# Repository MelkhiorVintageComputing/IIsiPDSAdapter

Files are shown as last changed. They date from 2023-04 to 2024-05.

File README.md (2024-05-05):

# PDS Adapter for the Macintosh IIsi

This repository contains recreated PDS adapters for the Macintosh IIsi.

They include a small switch to select the FPU clock, either the CPU clock (20 MHz) or the on-board oscillator (whatever 5V, DIP-8 or DIP-14 oscillator is soldered).

## PLCC

MC68882 FPU tested and working at 20 MHz (system clock)

MC68882 FPU tested and working at 25 MHz (on-board oscillator).

MC68882 FPU tested at 32 MHz, but if the adapter is stand-alone Error 11 occurs when using the FPU. When a [IIsiFPGA](https://github.com/rdolbeau/IIsiFPGA) is plugged in the second slot, 32 MHz seems to work reliably. Current hypothesis is some signal integrity issue when no PDS board is plugged in the adapter.

## PGA

MC68882 FPU tested and working at 20 MHz (system clock)

MC68882 FPU tested and working at 40 MHz (on-board oscillator), using a genuine XC68882RC40

Also known to work at 40 MHz with a IIsiFPGA in the second slot.

## PGA-DUAL

MC68882 FPU tested and working at 20 MHz (system clock) alongside a IIsiFPGA ans IIsiSEthernet, although [with some questions about signal integrity and/or timings](https://68kmla.org/bb/index.php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).

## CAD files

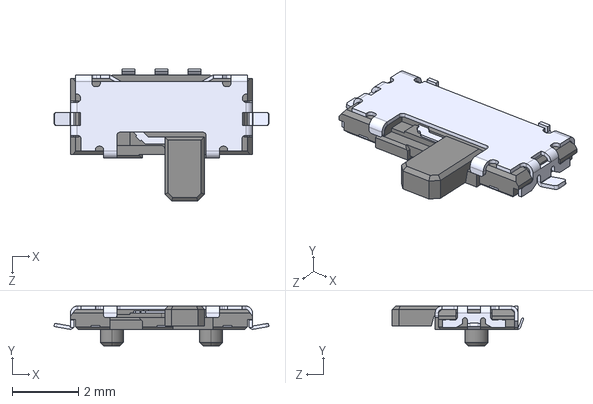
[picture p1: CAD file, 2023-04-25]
PGA_DUAL/SSAJ110100.step
6.50 x 1.20 x 3.98 mm

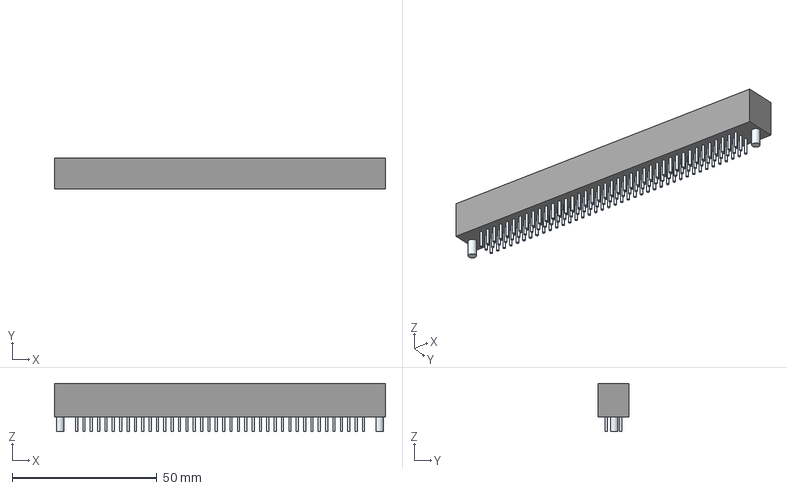
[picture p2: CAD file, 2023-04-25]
PGA_DUAL/5535098-5.stp
114.3 x 10.6 x 16.6 mm
Leads

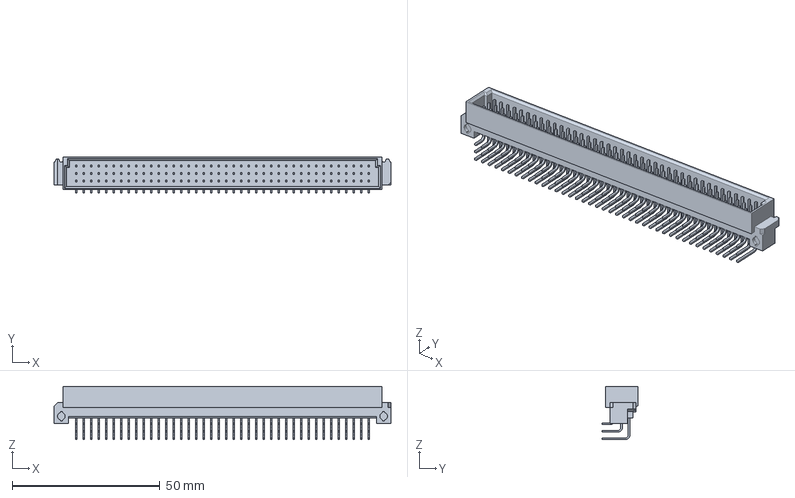
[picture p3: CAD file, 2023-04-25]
PGA_DUAL/650906-5.stp
114.2 x 12.1 x 18.0 mm

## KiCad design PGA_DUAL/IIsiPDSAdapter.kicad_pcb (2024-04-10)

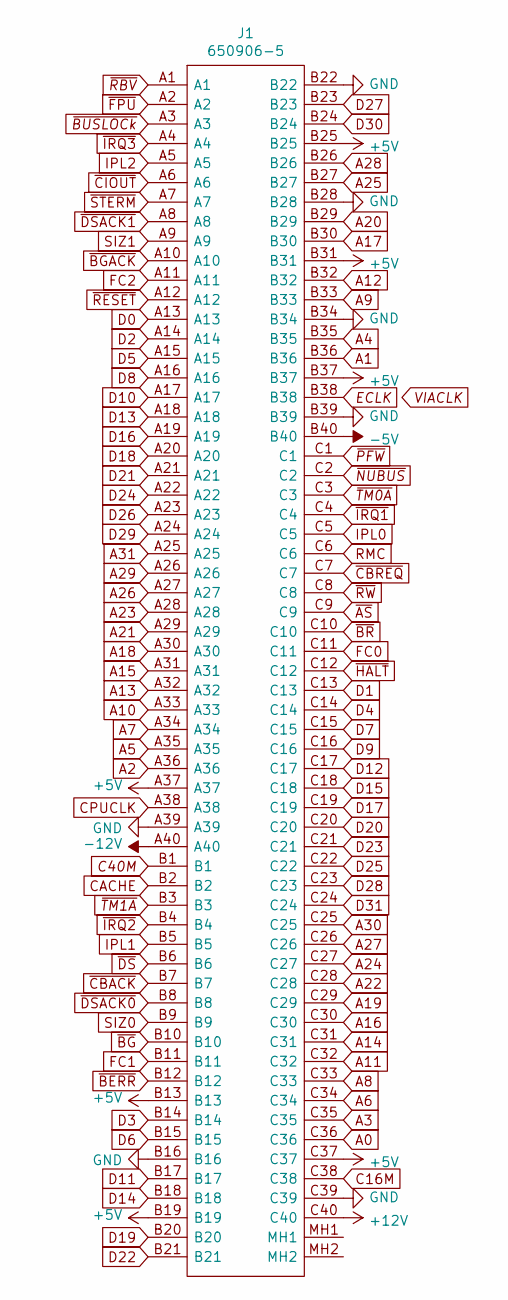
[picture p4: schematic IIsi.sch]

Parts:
J1: 650906-5; 6509065; Manufacturer_Part_Number 650906-5; Mouser Part Number 571-6509065

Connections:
+5V: J1.A37, J1.B13, J1.B19, J1.B25, J1.B31, J1.B37, J1.C37; also elsewhere on the board
+12V: J1.C40; also elsewhere on the board
-5V: J1.B40; also elsewhere on the board
-12V: J1.A40; also elsewhere on the board
A0: J1.C36; also elsewhere on the board
A1: J1.B36; also elsewhere on the board
A2: J1.A36; also elsewhere on the board
A3: J1.C35; also elsewhere on the board
A4: J1.B35; also elsewhere on the board
A5: J1.A35; also elsewhere on the board
A6: J1.C34; also elsewhere on the board
A7: J1.A34; also elsewhere on the board
A8: J1.C33; also elsewhere on the board
A9: J1.B33; also elsewhere on the board
A10: J1.A33; also elsewhere on the board
A11: J1.C32; also elsewhere on the board
A12: J1.B32; also elsewhere on the board
A13: J1.A32; also elsewhere on the board
A14: J1.C31; also elsewhere on the board
A15: J1.A31; also elsewhere on the board
A16: J1.C30; also elsewhere on the board
A17: J1.B30; also elsewhere on the board
A18: J1.A30; also elsewhere on the board
A19: J1.C29; also elsewhere on the board
A20: J1.B29; also elsewhere on the board
A21: J1.A29; also elsewhere on the board
A22: J1.C28; also elsewhere on the board
A23: J1.A28; also elsewhere on the board
A24: J1.C27; also elsewhere on the board
A25: J1.B27; also elsewhere on the board
A26: J1.A27; also elsewhere on the board
A27: J1.C26; also elsewhere on the board
A28: J1.B26; also elsewhere on the board
A29: J1.A26; also elsewhere on the board
A30: J1.C25; also elsewhere on the board
A31: J1.A25; also elsewhere on the board
C16M: J1.C38; also elsewhere on the board
C40M: J1.B1; also elsewhere on the board
CACHE: J1.B2; also elsewhere on the board
CPUCLK: J1.A38; also elsewhere on the board
D0: J1.A13; also elsewhere on the board
D1: J1.C13; also elsewhere on the board
D2: J1.A14; also elsewhere on the board
D3: J1.B14; also elsewhere on the board
D4: J1.C14; also elsewhere on the board
D5: J1.A15; also elsewhere on the board
D6: J1.B15; also elsewhere on the board
D7: J1.C15; also elsewhere on the board
D8: J1.A16; also elsewhere on the board
D9: J1.C16; also elsewhere on the board
D10: J1.A17; also elsewhere on the board
D11: J1.B17; also elsewhere on the board
D12: J1.C17; also elsewhere on the board
D13: J1.A18; also elsewhere on the board
D14: J1.B18; also elsewhere on the board
D15: J1.C18; also elsewhere on the board
D16: J1.A19; also elsewhere on the board
D17: J1.C19; also elsewhere on the board
D18: J1.A20; also elsewhere on the board
D19: J1.B20; also elsewhere on the board
D20: J1.C20; also elsewhere on the board
D21: J1.A21; also elsewhere on the board
D22: J1.B21; also elsewhere on the board
D23: J1.C21; also elsewhere on the board
D24: J1.A22; also elsewhere on the board
D25: J1.C22; also elsewhere on the board
D26: J1.A23; also elsewhere on the board
D27: J1.B23; also elsewhere on the board
D28: J1.C23; also elsewhere on the board
D29: J1.A24; also elsewhere on the board
D30: J1.B24; also elsewhere on the board
D31: J1.C24; also elsewhere on the board
ECLK: J1.B38; also elsewhere on the board
FC0: J1.C11; also elsewhere on the board
FC1: J1.B11; also elsewhere on the board
FC2: J1.A11; also elsewhere on the board
GND: J1.A39, J1.B16, J1.B22, J1.B28, J1.B34, J1.B39, J1.C39; also elsewhere on the board
IPL0: J1.C5; also elsewhere on the board
IPL1: J1.B5; also elsewhere on the board
IPL2: J1.A5; also elsewhere on the board
RMC: J1.C6; also elsewhere on the board
SIZ0: J1.B9; also elsewhere on the board
SIZ1: J1.A9; also elsewhere on the board
~AS: J1.C9; also elsewhere on the board
~BERR: J1.B12; also elsewhere on the board
~BG: J1.B10; also elsewhere on the board
~BGACK: J1.A10; also elsewhere on the board
~BR: J1.C10; also elsewhere on the board
~BUSLOCk: J1.A3; also elsewhere on the board
~CBACK: J1.B7; also elsewhere on the board
~CBREQ: J1.C7; also elsewhere on the board
~CIOUT: J1.A6; also elsewhere on the board
~DS: J1.B6; also elsewhere on the board
~DSACK0: J1.B8; also elsewhere on the board
~DSACK1: J1.A8; also elsewhere on the board
~FPU: J1.A2; also elsewhere on the board
~HALT: J1.C12; also elsewhere on the board
~IRQ1: J1.C4; also elsewhere on the board
~IRQ2: J1.B4; also elsewhere on the board
~IRQ3: J1.A4; also elsewhere on the board
~NUBUS: J1.C2; also elsewhere on the board
~PFW: J1.C1; also elsewhere on the board
~RBV: J1.A1; also elsewhere on the board
~RESET: J1.A12; also elsewhere on the board
~RW: J1.C8; also elsewhere on the board
~STERM: J1.A7; also elsewhere on the board
~TM0A: J1.C3; also elsewhere on the board
~TM1A: J1.B3; also elsewhere on the board

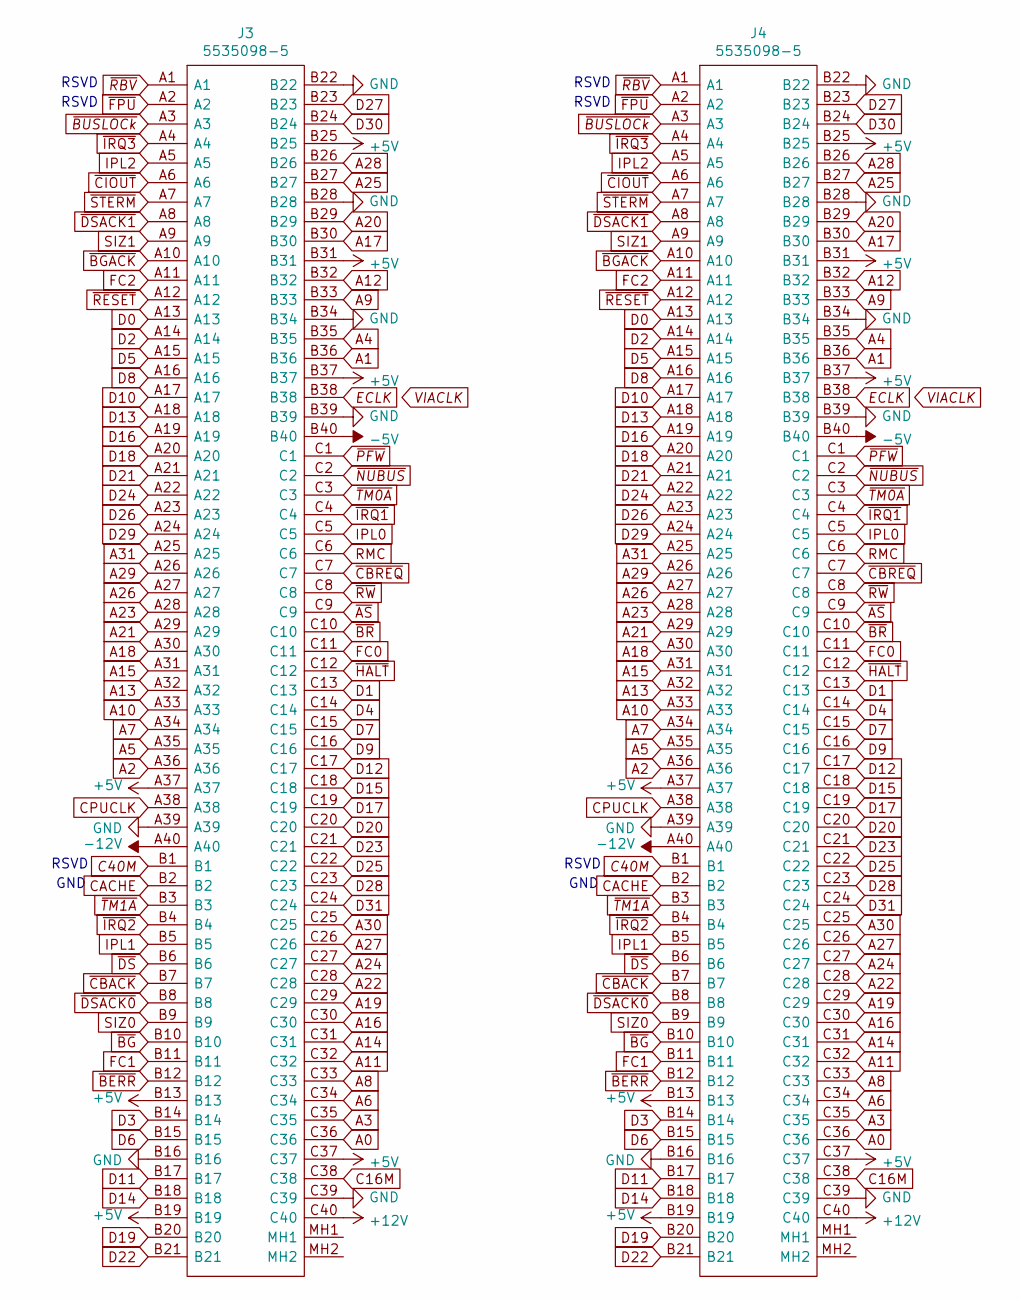
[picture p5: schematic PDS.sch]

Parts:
J3, J4: 5535098-5; Manufacturer_Part_Number 5535098-5; Mouser Part Number 571-5535098-5

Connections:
+5V: J3.A37, J3.B13, J3.B19, J3.B25, J3.B31, J3.B37, J3.C37, J4.A37, J4.B13, J4.B19, J4.B25, J4.B31, J4.B37, J4.C37; also elsewhere on the board
+12V: J3.C40, J4.C40; also elsewhere on the board
-5V: J3.B40, J4.B40; also elsewhere on the board
-12V: J3.A40, J4.A40; also elsewhere on the board
A0: J3.C36, J4.C36; also elsewhere on the board
A1: J3.B36, J4.B36; also elsewhere on the board
A2: J3.A36, J4.A36; also elsewhere on the board
A3: J3.C35, J4.C35; also elsewhere on the board
A4: J3.B35, J4.B35; also elsewhere on the board
A5: J3.A35, J4.A35; also elsewhere on the board
A6: J3.C34, J4.C34; also elsewhere on the board
A7: J3.A34, J4.A34; also elsewhere on the board
A8: J3.C33, J4.C33; also elsewhere on the board
A9: J3.B33, J4.B33; also elsewhere on the board
A10: J3.A33, J4.A33; also elsewhere on the board
A11: J3.C32, J4.C32; also elsewhere on the board
A12: J3.B32, J4.B32; also elsewhere on the board
A13: J3.A32, J4.A32; also elsewhere on the board
A14: J3.C31, J4.C31; also elsewhere on the board
A15: J3.A31, J4.A31; also elsewhere on the board
A16: J3.C30, J4.C30; also elsewhere on the board
A17: J3.B30, J4.B30; also elsewhere on the board
A18: J3.A30, J4.A30; also elsewhere on the board
A19: J3.C29, J4.C29; also elsewhere on the board
A20: J3.B29, J4.B29; also elsewhere on the board
A21: J3.A29, J4.A29; also elsewhere on the board
A22: J3.C28, J4.C28; also elsewhere on the board
A23: J3.A28, J4.A28; also elsewhere on the board
A24: J3.C27, J4.C27; also elsewhere on the board
A25: J3.B27, J4.B27; also elsewhere on the board
A26: J3.A27, J4.A27; also elsewhere on the board
A27: J3.C26, J4.C26; also elsewhere on the board
A28: J3.B26, J4.B26; also elsewhere on the board
A29: J3.A26, J4.A26; also elsewhere on the board
A30: J3.C25, J4.C25; also elsewhere on the board
A31: J3.A25, J4.A25; also elsewhere on the board
C16M: J3.C38, J4.C38; also elsewhere on the board
C40M: J3.B1, J4.B1; also elsewhere on the board
CACHE: J3.B2, J4.B2; also elsewhere on the board
CPUCLK: J3.A38, J4.A38; also elsewhere on the board
D0: J3.A13, J4.A13; also elsewhere on the board
D1: J3.C13, J4.C13; also elsewhere on the board
D2: J3.A14, J4.A14; also elsewhere on the board
D3: J3.B14, J4.B14; also elsewhere on the board
D4: J3.C14, J4.C14; also elsewhere on the board
D5: J3.A15, J4.A15; also elsewhere on the board
D6: J3.B15, J4.B15; also elsewhere on the board
D7: J3.C15, J4.C15; also elsewhere on the board
D8: J3.A16, J4.A16; also elsewhere on the board
D9: J3.C16, J4.C16; also elsewhere on the board
D10: J3.A17, J4.A17; also elsewhere on the board
D11: J3.B17, J4.B17; also elsewhere on the board
D12: J3.C17, J4.C17; also elsewhere on the board
D13: J3.A18, J4.A18; also elsewhere on the board
D14: J3.B18, J4.B18; also elsewhere on the board
D15: J3.C18, J4.C18; also elsewhere on the board
D16: J3.A19, J4.A19; also elsewhere on the board
D17: J3.C19, J4.C19; also elsewhere on the board
D18: J3.A20, J4.A20; also elsewhere on the board
D19: J3.B20, J4.B20; also elsewhere on the board
D20: J3.C20, J4.C20; also elsewhere on the board
D21: J3.A21, J4.A21; also elsewhere on the board
D22: J3.B21, J4.B21; also elsewhere on the board
D23: J3.C21, J4.C21; also elsewhere on the board
D24: J3.A22, J4.A22; also elsewhere on the board
D25: J3.C22, J4.C22; also elsewhere on the board
D26: J3.A23, J4.A23; also elsewhere on the board
D27: J3.B23, J4.B23; also elsewhere on the board
D28: J3.C23, J4.C23; also elsewhere on the board
D29: J3.A24, J4.A24; also elsewhere on the board
D30: J3.B24, J4.B24; also elsewhere on the board
D31: J3.C24, J4.C24; also elsewhere on the board
ECLK: J3.B38, J4.B38; also elsewhere on the board
FC0: J3.C11, J4.C11; also elsewhere on the board
FC1: J3.B11, J4.B11; also elsewhere on the board
FC2: J3.A11, J4.A11; also elsewhere on the board
GND: J3.A39, J3.B16, J3.B22, J3.B28, J3.B34, J3.B39, J3.C39, J4.A39, J4.B16, J4.B22, J4.B28, J4.B34, J4.B39, J4.C39; also elsewhere on the board
IPL0: J3.C5, J4.C5; also elsewhere on the board
IPL1: J3.B5, J4.B5; also elsewhere on the board
IPL2: J3.A5, J4.A5; also elsewhere on the board
RMC: J3.C6, J4.C6; also elsewhere on the board
SIZ0: J3.B9, J4.B9; also elsewhere on the board
SIZ1: J3.A9, J4.A9; also elsewhere on the board
~AS: J3.C9, J4.C9; also elsewhere on the board
~BERR: J3.B12, J4.B12; also elsewhere on the board
~BG: J3.B10, J4.B10; also elsewhere on the board
~BGACK: J3.A10, J4.A10; also elsewhere on the board
~BR: J3.C10, J4.C10; also elsewhere on the board
~BUSLOCk: J3.A3, J4.A3; also elsewhere on the board
~CBACK: J3.B7, J4.B7; also elsewhere on the board
~CBREQ: J3.C7, J4.C7; also elsewhere on the board
~CIOUT: J3.A6, J4.A6; also elsewhere on the board
~DS: J3.B6, J4.B6; also elsewhere on the board
~DSACK0: J3.B8, J4.B8; also elsewhere on the board
~DSACK1: J3.A8, J4.A8; also elsewhere on the board
~FPU: J3.A2, J4.A2; also elsewhere on the board
~HALT: J3.C12, J4.C12; also elsewhere on the board
~IRQ1: J3.C4, J4.C4; also elsewhere on the board
~IRQ2: J3.B4, J4.B4; also elsewhere on the board
~IRQ3: J3.A4, J4.A4; also elsewhere on the board
~NUBUS: J3.C2, J4.C2; also elsewhere on the board
~PFW: J3.C1, J4.C1; also elsewhere on the board
~RBV: J3.A1, J4.A1; also elsewhere on the board
~RESET: J3.A12, J4.A12; also elsewhere on the board
~RW: J3.C8, J4.C8; also elsewhere on the board
~STERM: J3.A7, J4.A7; also elsewhere on the board
~TM0A: J3.C3, J4.C3; also elsewhere on the board
~TM1A: J3.B3, J4.B3; also elsewhere on the board

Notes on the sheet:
GND
RSVD

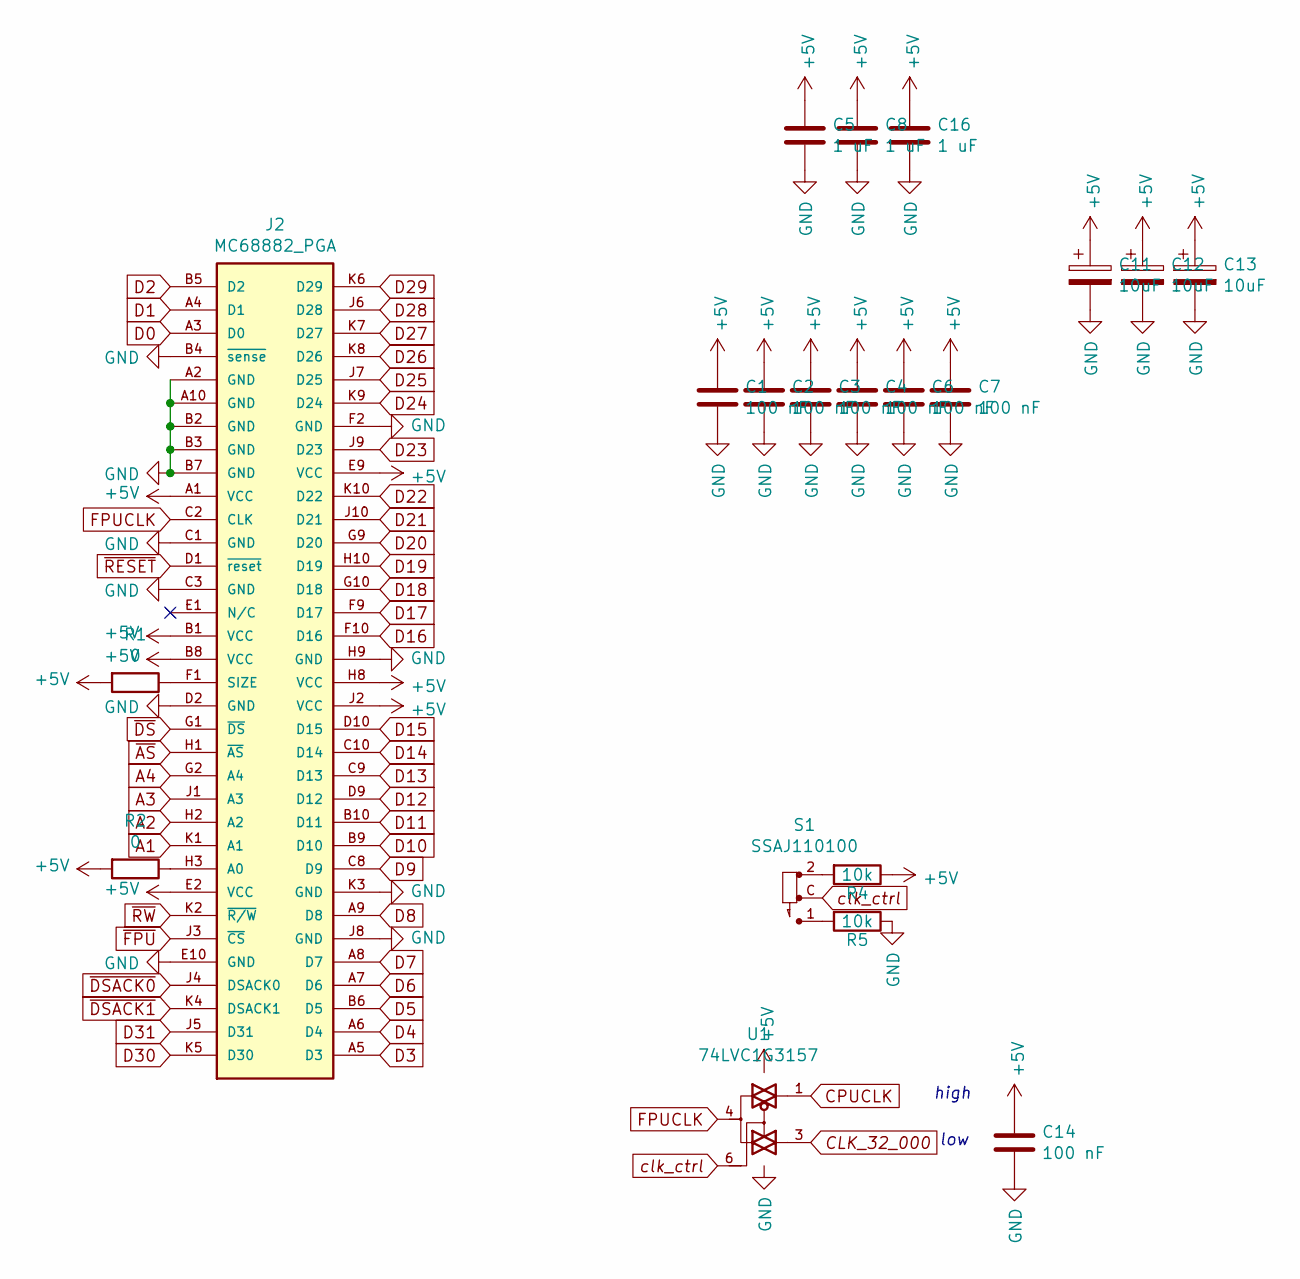
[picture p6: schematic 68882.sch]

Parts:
C1, C2, C3, C4, C6, C7, C14: 100 nF; C_0603_1608Metric; MPN CC0603KRX7R9BB104
C5, C8, C16: 1 uF; C_0603_1608Metric; MPN CL10A105KB8NNNC
C11, C12, C13: 10uF; CP_EIA-3216-18_Kemet-A; MPN TAJA106K016RNJ
J2: MC68882_PGA; MPN 510-83-068-10-061101
R1, R2: 0; R_0603_1608Metric; MPN 0603WAF0000T5E
R4, R5: 10k; R_0603_1608Metric; MPN 0603WAF1002T5E
S1: SSAJ110100; SW_SSAJ110100; MPN SSAJ110100
U1: 74LVC1G3157; SOT-23-6; MPN SN74LVC1G3157DBVR

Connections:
+5V: C1.1, C2.1, C3.1, C4.1, C5.1, C6.1, C7.1, C8.1, C11.1, C12.1, C13.1, C14.1, C16.1, J2.A1 (VCC), J2.B1 (VCC), J2.B8 (VCC), J2.E2 (VCC), J2.E9 (VCC), J2.H8 (VCC), J2.J2 (VCC), R1.2, R2.2, R4.1, U1.5 (VCC); also elsewhere on the board
A1: J2.K1 (A1); also elsewhere on the board
A2: J2.H2 (A2); also elsewhere on the board
A3: J2.J1 (A3); also elsewhere on the board
A4: J2.G2 (A4); also elsewhere on the board
CLK_32_000: U1.3; also elsewhere on the board
CPUCLK: U1.1; also elsewhere on the board
D0: J2.A3 (D0); also elsewhere on the board
D1: J2.A4 (D1); also elsewhere on the board
D2: J2.B5 (D2); also elsewhere on the board
D3: J2.A5 (D3); also elsewhere on the board
D4: J2.A6 (D4); also elsewhere on the board
D5: J2.B6 (D5); also elsewhere on the board
D6: J2.A7 (D6); also elsewhere on the board
D7: J2.A8 (D7); also elsewhere on the board
D8: J2.A9 (D8); also elsewhere on the board
D9: J2.C8 (D9); also elsewhere on the board
D10: J2.B9 (D10); also elsewhere on the board
D11: J2.B10 (D11); also elsewhere on the board
D12: J2.D9 (D12); also elsewhere on the board
D13: J2.C9 (D13); also elsewhere on the board
D14: J2.C10 (D14); also elsewhere on the board
D15: J2.D10 (D15); also elsewhere on the board
D16: J2.F10 (D16); also elsewhere on the board
D17: J2.F9 (D17); also elsewhere on the board
D18: J2.G10 (D18); also elsewhere on the board
D19: J2.H10 (D19); also elsewhere on the board
D20: J2.G9 (D20); also elsewhere on the board
D21: J2.J10 (D21); also elsewhere on the board
D22: J2.K10 (D22); also elsewhere on the board
D23: J2.J9 (D23); also elsewhere on the board
D24: J2.K9 (D24); also elsewhere on the board
D25: J2.J7 (D25); also elsewhere on the board
D26: J2.K8 (D26); also elsewhere on the board
D27: J2.K7 (D27); also elsewhere on the board
D28: J2.J6 (D28); also elsewhere on the board
D29: J2.K6 (D29); also elsewhere on the board
D30: J2.K5 (D30); also elsewhere on the board
D31: J2.J5 (D31); also elsewhere on the board
FPUCLK: J2.C2 (CLK), U1.4
GND: C1.2, C2.2, C3.2, C4.2, C5.2, C6.2, C7.2, C8.2, C11.2, C12.2, C13.2, C14.2, C16.2, J2.A2 (GND), J2.A10 (GND), J2.B2 (GND), J2.B3 (GND), J2.B4 (~sense), J2.B7 (GND), J2.C1 (GND), J2.C3 (GND), J2.D2 (GND), J2.E10 (GND), J2.F2 (GND), J2.H9 (GND), J2.J8 (GND), J2.K3 (GND), R5.1, U1.2 (GND); also elsewhere on the board
unnamed: J2.F1 (SIZE), R1.1
unnamed: J2.H3 (A0), R2.1
unnamed: R4.2, S1.2
unnamed: R5.2, S1.1
clk_ctrl: S1.C, U1.6
~AS: J2.H1 (~AS); also elsewhere on the board
~DS: J2.G1 (~DS); also elsewhere on the board
~DSACK0: J2.J4 (DSACK0); also elsewhere on the board
~DSACK1: J2.K4 (DSACK1); also elsewhere on the board
~FPU: J2.J3 (~CS); also elsewhere on the board
~RESET: J2.D1 (~reset); also elsewhere on the board
~RW: J2.K2 (~R/W); also elsewhere on the board

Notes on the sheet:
low
high

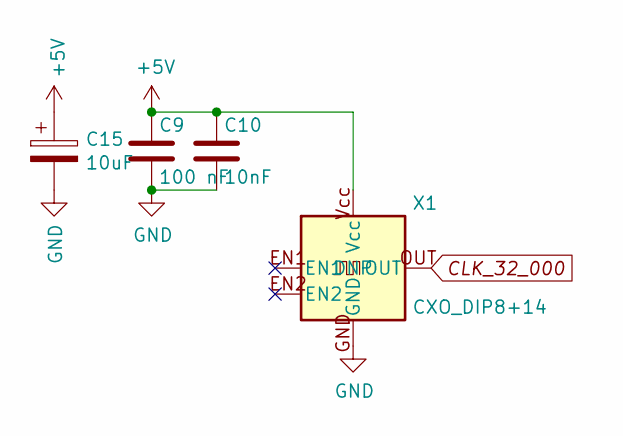
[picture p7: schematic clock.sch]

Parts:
C11: 100 nF; C_0603_1608Metric; MPN CC0603KRX7R9BB104; Mouser 603-CC603KRX7R8BB104
C13: 10nF; C_0603_1608Metric; MPN 0603B103K500NT; Mouser 603-CC603KRX7R8BB103
C15: 10uF; CP_EIA-3216-18_Kemet-A; MPN TAJA106K016RNJ
X1: CXO_DIP8+14

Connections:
+5V: C11.1, C13.1, C15.1, X1.Vcc; also elsewhere on the board
CLK_32_000: X1.OUT; also elsewhere on the board
GND: C11.2, C13.2, C15.2, X1.GND; also elsewhere on the board

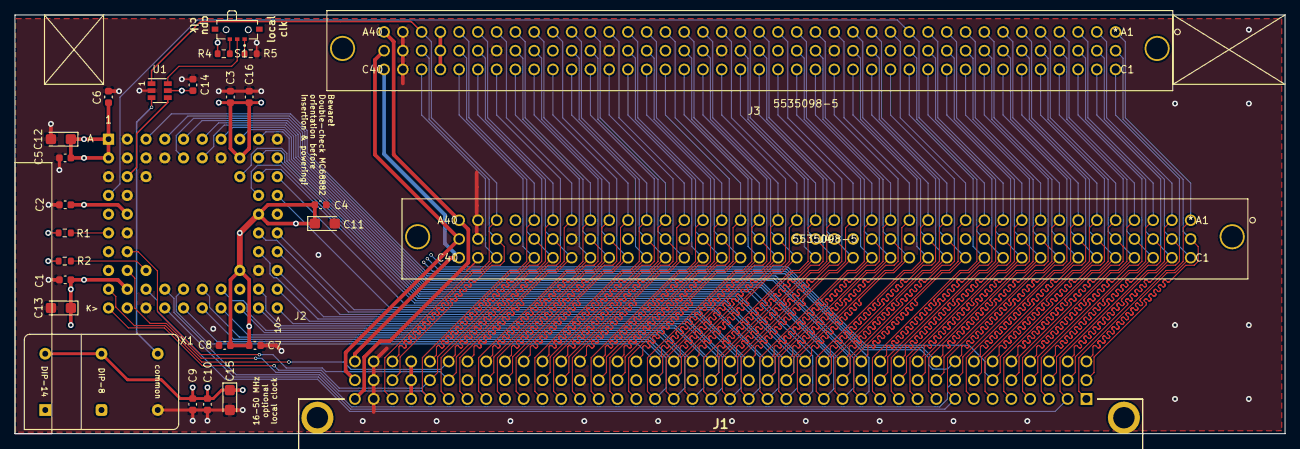
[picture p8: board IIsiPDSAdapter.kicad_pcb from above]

Board: 4 copper layers, 172.0 x 56.7 mm, 27 parts (0 on the bottom side), 115 nets.

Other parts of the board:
C9: 100 nF; C_0603_1608Metric
C10: 10nF; C_0603_1608Metric

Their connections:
+5V: C9.1, C10.1; also elsewhere on the board
GND: C9.2, C10.2; also elsewhere on the board

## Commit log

2023-04-25 initial import
    [5535098-5.stp, 650906-5.stp, 68882.sch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]
2023-05-01 PGA draft
    [5535098-5.stp, 650906-5.stp, 68882.sch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]
2023-05-01 minor fixes
    [IIsiPDSAdapter.kicad_pcb]
2024-01-08 push dual, completely untested!
    [5535098-5.stp, 650906-5.stp, 68882.sch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]

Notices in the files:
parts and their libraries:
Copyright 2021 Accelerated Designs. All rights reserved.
